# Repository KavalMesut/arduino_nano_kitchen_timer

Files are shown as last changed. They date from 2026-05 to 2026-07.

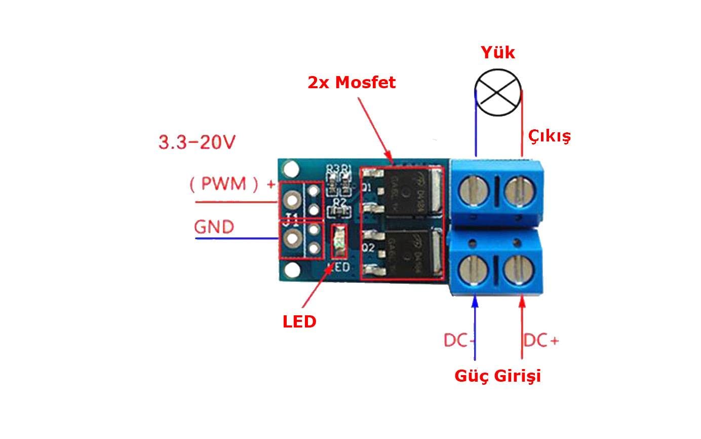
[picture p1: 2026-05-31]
mosfet.jpg

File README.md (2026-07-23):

# ⏳Mutfak Geri Sayım Alarmı (Arduino Nano & 18650 Li-ion Şarjlı Sürüm)

Bu proje, mutfakta çay demleme, yemek pişirme veya zaman gerektiren diğer hassas işler için tasarlanmış, döner enkoder (rotary encoder) kontrollü, TM1637 4 haneli 7 segment göstergeli, **18650 2200 mAh Li-ion Pil & LX-LCBST (TP4056 + DC-DC 5V Yükseltici)** şarj sistemli ve emniyetli MOSFET sürücülü 4 Ohm 5W güçlü hoparlör barındıran üst segment bir mutfak geri sayım alarmıdır.

Tüm sistem, taşınabilir şarjlı yapısı ve donanımsal/yazılımsal emniyet tedbirleriyle yüksek ses seviyesinde dahi kilitlenmemesi veya sıfırlanmaması için optimize edilmiştir.

---

## 🛠️ Kullanılan Malzemeler (BOM Listesi)

1. **Arduino Nano (CH340 veya Orijinal)**: Sistem durum makinesini (State Machine) yöneten ana kontrolcü.
2. **EC11 Bare Rotary Encoder (Döner Enkoder)**: Entegre mekanik butonu olan, süre ayarlamak ve komut vermek için kullanılan 360 derece dönebilen seçici.
3. **TM1637 4 Haneli 7 Segment Gösterge Modülü**: Zamanı `DAKİKA : SANİYE` (MM:SS) formatında ve batarya durumunu (`b-85`, `Lo`) gösteren ekran.
4. **4 Ohm 5W Güçlü Hoparlör**: Mutfaktaki gürültüde dahi çok net ve yüksek sesle duyulabilen kaliteli hoparlör.
5. **D4184 Dual MOSFET Anahtar Modülü**: Hoparlörü doğrudan Arduino pininden çekilemeyecek yüksek akımla, 5V hattından güvenle ve yüksek sesle tetiklemek için kullanılan mosfet kartı.
6. **18650 2200 mAh Li-ion Pil**: Şarj edilebilir ana güç kaynağı.
7. **LX-LCBST (TP4056 + DC-DC 5V Step-Up Yükseltici Modülü)**: Type-C şarj girişli, korumalı ve voltajı 5.0V'a yükseltilmiş şarj devresi.
8. **Sürgülü Güç Anahtarı (ON/OFF Switch)**: Cihazı tamamen açıp kapatan anahtar (LX-LCBST VO+ çıkışına seri bağlı).
9. **Emniyet Direnci**: Hoparlör bobinini ve MOSFET'i korurken yüksek ses sağlayan **2 adet 10 Ohm 1W paralel bağlı metal film koruma direnci (5Ω / 2W eşdeğer)**.
10. **A0 & A1 Koruma Dirençleri**: A0 (pil okuma) ve A1 (şarj algılama) pinleri öncesinde parazit beslemeyi ve pin hasarını önleyen **10kΩ seri koruma dirençleri**.
10. **Özel Tasarım 3D Kutu**: İçten içe 80mm x 140mm (Dıştan dışa 84mm x 144mm x 30mm) boyutlarında, baklava/diamond desenli hoparlör ızgaralı, Type-C şarj soketli ve M3 pirinç inserts (ısı kovanı) uyumlu gövde.

---

## ⚠️ KRİTİK TRİMPOT KALİBRASYON UYARISI

**LX-LCBST modülünün `VO+` / `VO-` çıkışlarını Arduino veya diğer kartlara bağlamadan önce;**
Modül üzerindeki minyatür trimpotu çevirerek `VO+` çıkış voltajını bir multimetre (avometre) ile ölçüp **tam 5.0 Volt'a** ayarlamalısınız! Aksi takdirde modül yüksek voltaj (9V/12V) vererek Arduino'ya zarar verebilir.

---

## 📐 3D Kutu ve Mekanik Özellikler

Kutu tasarımı OpenSCAD yardımıyla tamamen parametrik ve sağlam olarak geliştirilmiştir:
* **Gövde (`kutu_govde.stl`)**: Solid ön yüzey, 50mm baklava desenli hoparlör ızgarası, Type-C şarj soket yuvası, sağ yanda güç anahtarı yuvası ve köşelere tamamen gömülerek mukavemeti artırılmış **M3 pirinç ısı kovanı (heat-set inserts)** yuvaları barındırır.
* **Kapak (`kutu_kapak.stl`)**: Solid arka kapak, havşa başlı M3 vidaların sıfıra sıfır oturması için tasarlanmış delik yapıları.

---

## 🔋 Batarya & Şarj Ekran Özellikleri (TM1637)

* **2 Saniye Basılı Tutma (Batarya Kontrolü)**: Butona 2 saniye basılı tuttuğunuzda ekranda **tam 1 saniye boyunca** anlık batarya yüzdesi gösterilir (Örn: **`b-85`** = %85 pil), 1 saniye sonra ekran eski durumuna döner.
* **Düşük Batarya Uyarısı (%10 Altında `Lo` Uyarısı)**: Batarya seviyesi **%10'un altına** düştüğünde, her yeni zaman ayarlama girişiminde (enkoder her çevrildiğinde) ekranda **`Lo`** yazısı yanıp söner ve kısa bir **uyarı bip sesi** verilir.
* **Şarj Girişi Algılama**: Type-C takıldığında Arduino şarj modunu otomatik algılar.

---

## ⚡ Donanım Bağlantı Tablosu

| Kaynak Modül | Pin / Bağlantı | Hedef Pin | İşlev |
| :--- | :--- | :--- | :--- |
| **18650 Li-ion Pil** | Artı (+) / B+ | LX-LCBST B+ / **Arduino A0** | Batarya Besleme & Voltaj Okuma |
| **18650 Li-ion Pil** | Eksi (-) / B- | LX-LCBST B- | Batarya Şasi |
| **LX-LCBST Modülü** | VO+ (5V Yükseltici) | ON/OFF Anahtarı $\rightarrow$ **Ortak +5V** | 5.0V Sistem Besleme |
| **LX-LCBST Modülü** | VO- (GND) | **Ortak GND Rayı** | Sistem Şasi |
| **LX-LCBST Modülü** | IN+ (Type-C 5V) | 10k Direnç $\rightarrow$ **Arduino A1** | Şarj Girişi Algılama |
| **EC11 Enkoder** | Out A (3'lü Grup) | **Arduino D2** | Kesme 0 Sinyali |
| **EC11 Enkoder** | Out B (3'lü Grup) | **Arduino D3** | Kesme 1 Sinyali |
| **EC11 Enkoder** | Switch (2'li Grup) | **Arduino D4** | Buton Girişi |
| **TM1637 Ekran** | CLK / DIO | **Arduino D5 / D6** | Ekran Saat & Veri Hattı |
| **D4184 MOSFET** | (PWM) + Sinyal | **Arduino D9** | Timer 1 Donanımsal PWM Sinyali |

---

## 🚀 Derleme ve Kurulum

1. Bilgisayarınıza **Arduino IDE** kurun.
2. Arduino IDE içerisindeki **Kütüphane Yöneticisi (Library Manager)** menüsünden **TM1637** (Avishay Orpaz) kütüphanesini kurun.
3. [kitchen_timer.ino](file:///c:/Users/kaval/OneDrive/Desktop/geri%20say%C4%B1m%20nano/kitchen_timer/kitchen_timer.ino) dosyasını Arduino IDE ile açın.
4. Kart tipini **Arduino Nano**, işlemciyi ise klon kartlar için **ATmega328P (Old Bootloader)** seçin.
5. Uygun COM portunu belirleyip kodu kartınıza yükleyin.

---

## 📁 Proje Dosyaları Yapısı

* 📁 **`kitchen_timer/`**: Arduino kaynak dosyalarının bulunduğu klasör.
  * 📄 **`kitchen_timer.ino`**: Durum makinesi, kesme tabanlı enkoder okuma, MOSFET alarm ve A0/A1 batarya kodları.
* 📄 **`kutu_tasarimi.scad`**: OpenSCAD kutu tasarımının kaynak parametrik dosyası.
* 📄 **`kutu_govde.stl`**: Kutu gövdesinin 3D baskıya hazır modeli.
* 📄 **`kutu_kapak.stl`**: Arka kapağın 3D baskıya hazır modeli.
* 📄 **`baglanti_semasi.pdf` / `.tex`**: Detaylı donanım bağlantı kılavuzu ve şemaları.
* 📄 **`README.md`**: Proje açıklama ve kurulum dokümanı.

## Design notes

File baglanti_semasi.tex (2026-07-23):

\documentclass[12pt,a4paper]{article}
\usepackage[utf8]{inputenc}

\title{Arduino Nano ile Mutfak Geri Sayim Alarmi\\Sarjli/Bataryali Donanim Baglanti Kilavuzu}
\author{Mutfak Zamanlayici Projesi}
\date{23 Temmuz 2026}

\begin{document}

\maketitle

\section{Giris ve Onemli Guvenlik Uyarilari}
Bu belge, Arduino Nano tabanli, TM1637 7 segment gostergeli, EC11 doner enkoder kontrollu, D4184 MOSFET suruculu ve \textbf{18650 2200 mAh Li-ion Pil + LX-LCBST (TP4056 + DC-DC 5V Yukseltici)} sarj sistemli mutfak geri sayim alarminin baglanti detaylarini icermektedir.

\subsection{TRIMPOT KALIBRASYON UYARISI (COK ONEMLI!)}
\textbf{LX-LCBST modulunun VO+ / VO- cikislarini Arduino, ekran veya MOSFET kartina BAGLAMADAN ONCE;}
Type-C kablosunu veya pili takip bir multimetre (avometre) ile \textbf{VO+} cikis voltajini olcun. Modul uzerindeki minyatur trimpotu cevirerek cikis voltajini \textbf{tam 5.0 Volt'a} ayarlayin! Fabrikasyon olarak 9V/12V ayarli gelebilir; ayarlamadan baglarsaniz Arduino kartiniz ve ekraniniz yanabilir!

\subsection{Hoparlor ve MOSFET Emniyet Direnci}
4 Ohm 5W gucundeki hoparlorun yuksek anlik akim cekerek Arduino'ya reset attirmasini ve hoparlor bobininin zarar gormesini engellemek amaciyla hoparlor hattina seri olarak \textbf{10 Ohm (1W)} koruma direnci baglanmalidir.

\section{Adim Adim Baglanti Talimatlari}

\begin{enumerate}
    \item \textbf{Guc Kaynagi ve Sarj Sistemi (LX-LCBST + 18650 Pil):}
    \begin{itemize}
        \item \textbf{B+} $\rightarrow$ 18650 Pilin Arti (+) kutbuna ve ayni zamanda Arduino Nano \textbf{A0} pinine (Batarya voltaji okuma).
        \item \textbf{B-} $\rightarrow$ 18650 Pilin Eksi (-) kutbuna.
        \item \textbf{VO+} $\rightarrow$ Surgulu Guc Anahtarinin (ON/OFF) bacak 1'ine. Anahtarin bacak 2'si ortak \textbf{+5V} rayina baglanir.
        \item \textbf{VO-} $\rightarrow$ Ortak \textbf{GND} sasi rayina.
        \item \textbf{IN+} (Type-C Girisi) $\rightarrow$ 10k koruma direnci uzerinden Arduino Nano \textbf{A1} pinine (Sarj algilama).
        \item \textbf{IN-} (Type-C Sasi) $\rightarrow$ Ortak \textbf{GND} sasi rayina.
    \end{itemize}

    \item \textbf{Ciplak Doner Enkoder (EC11) Baglantilari:}
    \begin{itemize}
        \item \textbf{Out A} (Ust Pin - 3'lu grup) $\rightarrow$ Arduino Nano \textbf{D2}
        \item \textbf{GND} (Orta Pin - 3'lu grup) $\rightarrow$ Ortak \textbf{GND}
        \item \textbf{Out B} (Alt Pin - 3'lu grup) $\rightarrow$ Arduino Nano \textbf{D3}
        \item \textbf{Switch} (Sol Pin - 2'li grup) $\rightarrow$ Arduino Nano \textbf{D4}
        \item \textbf{GND} (Sag Pin - 2'li grup) $\rightarrow$ Ortak \textbf{GND}
    \end{itemize}

    \item \textbf{TM1637 Gosterge Baglantilari:}
    \begin{itemize}
        \item \textbf{CLK} $\rightarrow$ Arduino Nano \textbf{D5}
        \item \textbf{DIO} $\rightarrow$ Arduino Nano \textbf{D6}
        \item \textbf{VCC} $\rightarrow$ Ortak \textbf{+5V}
        \item \textbf{GND} $\rightarrow$ Ortak \textbf{GND}
    \end{itemize}

    \item \textbf{D4184 MOSFET Surucu \& Hoparlor Baglantilari:}
    \begin{itemize}
        \item \textbf{(PWM) +} Sinyal $\rightarrow$ Arduino Nano \textbf{D9}
        \item \textbf{Sinyal GND} $\rightarrow$ Ortak \textbf{GND}
        \item \textbf{DC+ (Klemens Alt Sag)} $\rightarrow$ Ortak \textbf{+5V}
        \item \textbf{DC- (Klemens Alt Sol)} $\rightarrow$ Ortak \textbf{GND}
        \item \textbf{Cikis+ (Klemens Ust Sag)} $\rightarrow$ Hoparlor (+)
        \item \textbf{Cikis- (Klemens Ust Sol)} $\rightarrow$ 10 Ohm 1W Direnc ucu 1
        \item 10 Ohm 1W Direnc ucu 2 $\rightarrow$ Hoparlor (-)
    \end{itemize}
\end{enumerate}

\newpage
\section{Donanim Baglanti Tablosu}

\begin{table}[h!]
\centering
\begin{tabular}{|l|l|l|l|}
\hline
\textbf{Kaynak Modul} & \textbf{Pin Adi} & \textbf{Hedef Pin / Baglanti} & \textbf{Islev} \\ \hline
18650 Li-ion Pil & Arti (+) / B+ & LX-LCBST B+ / Arduino A0 & Batarya Besleme \& Voltaj Okuma \\
18650 Li-ion Pil & Eksi (-) / B- & LX-LCBST B- & Batarya Sasi Baglantisi \\
LX-LCBST Modulu & VO+ (5V Cikis) & ON/OFF Anahtari $\rightarrow$ Ortak +5V & Ana Sistem Guc Cikisi \\
LX-LCBST Modulu & VO- (GND Cikis) & Ortak GND Sasi Rayi & Sistem Sasi Baglantisi \\
LX-LCBST Modulu & IN+ (Sarj Girisi) & 10k Direnc $\rightarrow$ Arduino A1 & Sarj Kablosu Algilama \\
LX-LCBST Modulu & IN- (Sarj Sasi) & Ortak GND Sasi Rayi & Sarj Girisi Sasisi \\ \hline
EC11 Enkoder & Out A (Ust - 3'lu) & Arduino Nano D2 & Zamanlama Girisi (Kesme 0) \\
EC11 Enkoder & GND (Orta - 3'lu) & Ortak GND & Enkoder Sasi \\
EC11 Enkoder & Out B (Alt - 3'lu) & Arduino Nano D3 & Yon Algilama (Kesme 1) \\
EC11 Enkoder & Switch (Sol - 2'li) & Arduino Nano D4 & Buton Girisi \\
EC11 Enkoder & GND (Sag - 2'li) & Ortak GND & Buton Sasi \\ \hline
TM1637 Ekran & CLK & Arduino Nano D5 & Gosterge Saat Sinyali \\
TM1637 Ekran & DIO & Arduino Nano D6 & Gosterge Veri Hatti \\
TM1637 Ekran & VCC & Ortak +5V Rayi & Gosterge Gucu \\
TM1637 Ekran & GND & Ortak GND Rayi & Gosterge Sasisi \\ \hline
D4184 MOSFET & (PWM) + Sinyal & Arduino Nano D9 & Sinyal Tetikleme (Timer 1) \\
D4184 MOSFET & Sinyal GND & Ortak GND & Ortak Sasi \\
D4184 MOSFET & DC+ (Alt Sag) & Ortak +5V Rayi & Hoparlor Guc Beslemesi \\
D4184 MOSFET & DC- (Alt Sol) & Ortak GND Rayi & Hoparlor Guc Sasisi \\
D4184 MOSFET & Cikis+ / Cikis- & 10 Ohm 1W Direnc ile Hoparlor & 5W Hoparlor Surucusu \\ \hline
\end{tabular}
\end{table}

\end{document}

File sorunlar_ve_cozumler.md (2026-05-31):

# 🛠️ Mutfak Geri Sayım Alarmı: Sorunlar ve Çözümler Kılavuzu

Bu belge, Arduino Nano tabanlı Premium Mutfak Geri Sayım Alarmı projesinin geliştirilmesi, montajı ve testleri sırasında karşılaşılan kritik elektriksel, donanımsal ve yazılımsal sorunları ve bu sorunların kesin çözümlerini bir araya getirmektedir. Gelecekteki bakım ve benzer projeler için bir başvuru kılavuzudur.

---

## 📌 1. Döner Enkoder Çift Atlama ve Gürültü Sorunu (Debouncing)

### 🔴 Belirti:
Enkoder döndürüldüğünde değerlerin kararsız artması/azalması, ara sıra çift atlamalar yapması veya hızlı çevrildiğinde adımların kaçırılması.

### 🔍 Analiz:
Mekanik döner enkoderler (bare EC11) döndürülürken elektriksel kontakları anlık olarak ark yapar (contact bounce). Bu yüksek frekanslı gürültüler kesme (interrupt) servisleri tarafından gerçek dönüş adımları gibi algılanır. 
* **Çok yüksek gürültü filtresi (örn. 20ms)** hızlı çevirmelerde adımların kaçırılmasına yol açar.
* **Çok düşük filtre (örn. 4ms)** gürültülü klon enkoderlerde çift atlamalara neden olur.

### 🟢 Kesin Çözüm:
Kesme servisi içerisindeki gürültü önleme filtresi **30 ms** olarak optimize edildi. Bu değer, klon enkoderlerin mekanik gürültülerini tamamen süzerken, normal çevrim hızlarındaki tüm adımların kararlı şekilde yakalanmasını sağlar:
```cpp
void encoderISR() {
  static unsigned long lastInterruptTime = 0;
  unsigned long interruptTime = millis();
  
  if (interruptTime - lastInterruptTime > 30) { // 30ms Kararlı Debounce
    int clkVal = digitalRead(PIN_ENC_CLK);
    int dtVal = digitalRead(PIN_ENC_DT);
    if (clkVal != dtVal) {
      encoderDelta = 1;
    } else {
      encoderDelta = -1;
    }
    encoderMoved = true;
    lastInterruptTime = interruptTime;
  }
}
```

---

## 📌 2. MOSFET Hoparlör Sürücü Emniyeti (DC Akım Koruması)

### 🔴 Belirti:
Hoparlör bobininin aşırı ısınması, MOSFET modülünün ısınması veya adaptörün aşırı akım korumasına girerek sistemi kapatması.

### 🔍 Analiz:
4 Ohm empedansa sahip güçlü bir hoparlör, 5V DC gerilim altında doğrudan iletimde kalırsa $I = V / R = 5V / 4\Omega = 1.25A$ akım çeker. Arduino Nano'nun pini kilitlenir veya yazılım hatasıyla sürekli `HIGH` konumda kalırsa, hoparlör bobini sürekli DC akıma maruz kalarak yanabilir.

### 🟢 Kesin Çözüm:
1. **Donanımsal Koruma (Direnç Hilesi):** Hoparlöre seri olarak **4 adet 47 Ohm 1/4W direnç paralel bağlanarak** (~11.7 Ohm 1W) seri koruma direnci oluşturuldu. Bu, çekilen akımı sınırlandırarak bobini korur.
2. **Yazılımsal Koruma (DC Emniyeti):** Ses üretimi tamamen AC/Pulsed mantığında (Timer PWM) yapıldı. Alarm çalmadığı veya ses durduğu anda MOSFET tetikleme pini (D9) donanımsal ve yazılımsal olarak tamamen kapatılıp `LOW` seviyesine çekilir:
```cpp
void stopTonePWM() {
  TCCR1A = 0; // Donanımsal PWM bağlantısını kopar
  TCCR1B = 0;
  digitalWrite(PIN_MOSFET, LOW); // Emniyet için pini LOW yap (Akımı tamamen keser)
}
```

---

## 📌 3. Fiziksel Temassızlık ve Akustik Titreşim (Kablo Kopukluğu)

### 🔴 Belirti:
Tetikleme LED'i yandığı halde hoparlörden hiçbir ses gelmemesi.

### 🔍 Analiz:
Klemens vidalarının plastik yalıtkanı sıkıştırması, lehim çatlakları veya hoparlörün ürettiği yüksek mekanik titreşimin (vibrasyon) kabloları sarsması sonucu oluşan gizli temassızlıklar.

### 🟢 Teşhis ve Çözüm Yöntemi (Yavaş Sinyal Testi):
Frekans yerine saniyede bir yavaşça açılıp kapanan (Blink) bir sinyal üretilerek klemens ve hoparlör yolları test edildi. Sinyal yavaşlatıldığında hoparlörden gelen **"tık... tık..."** sesleri sayesinde kopuk olan kablo noktası fiziksel olarak kolayca tespit edildi:
```cpp
// Yavaş tetikleme ile kablo ve lehim kontrolü yapılmıştır:
digitalWrite(9, HIGH); delay(1000);
digitalWrite(9, LOW);  delay(1000);
```

---

## 📌 4. Sürekli Ekran Yazımı Kaynaklı Döngü (Loop) Yavaşlaması

### 🔴 Belirti:
Siren çalarken veya zaman akarken döner enkoderin geç tepki vermesi, sistem zamanlamasında milisaniyelik kaymalar (jitter) oluşması.

### 🔍 Analiz:
TM1637 gösterge modülü yazılımsal bit-bang (CLK ve DIO pinlerini sırayla HIGH/LOW yapıp mikrosaniye seviyesinde bekleyerek) veri gönderir. Ekran verisi her `loop()` döngüsünde sürekli baştan yazıldığında, döngü hızı saniyede sadece ~200 çevrime düşer. Bu da mikrodenetleyicinin diğer zamanlayıcı işlerini geciktirir.

### 🟢 Kesin Çözüm:
Ekran güncelleme mekanizması **Olay Güdümlü (Event-Driven)** hale getirildi. Ekran verileri sadece **süre, durum veya iki noktanın konumu gerçekten değiştiğinde** yazılır. Bu sayede loop hızı **saniyede 50.000+ çevrime çıkarıldı**, gecikmeler tamamen yok edildi.

---

## 📌 5. Rastgele Siren Kesilmeleri (Timer 1 `ICR1` Aşım Hatası)

### 🔴 Belirti:
Alarm çalarken, belirli aralıklarla olmayan, tamamen rastgele ve düzensiz milisaniyelik anlık ses kesilmeleri/pıtırtılar oluşması.

### 🔍 Analiz:
Siren tonunu 2500 Hz ile 3500 Hz arasında 100 ms'de bir değiştirmek için Timer 1'in **`ICR1` (Üst Sınır / TOP)** kaydedicisine yeni değer yazılır. 
* ATmega328P mimarisinde Fast PWM modunda (Mod 14) **`ICR1` kaydedicisi donanımsal çift-tamponlu (double-buffered) değildir.** Değer yazıldığı anda güncellenir.
* **Hata Durumu:** Frekansı değiştirirken eğer Timer 1 sayacı (`TCNT1`) o an yeni yazılan `ICR1` sınırını geçmişse (örn. TCNT1=600, yeni ICR1=571), sayaç üst sınırı kaçırır. Sınırı kaçırdığı için durmaz ve taa **65535'e kadar saymaya devam eder**.
* Bu durum, 2 MHz sayaç hızında tam **32.7 milisaniye** sürer ve bu süre zarfında MOSFET kapısı takılı kalarak **rastgele ve periyodik olmayan sessizlik/kesinti** oluşturur.

### 🟢 Kesin Çözüm:
Frekans (yani `ICR1`) her değiştiğinde, zamanlayıcı sayacı yazılımsal olarak **anında sıfırlanır (`TCNT1 = 0;`)**. Böylece sayaç asla yeni üst sınırı kaçırmaz ve geçişler faz-kesintisiz, tamamen pürüzsüz ve çıtırtısız olur:
```cpp
void startTonePWM(unsigned int frequency, int volumeLevel) {
  pinMode(PIN_MOSFET, OUTPUT);
  unsigned long top = 2000000UL / frequency;
  
  if (ICR1 != top) {
    ICR1 = top;
    TCNT1 = 0; // Sayacı sıfırlayarak TCNT1 > ICR1 aşımını engeller (Kesintileri sıfırlar!)
  }
  
  unsigned long ocr = (top * (unsigned long)(volumeLevel * volumeLevel)) / 200UL;
  if (ocr == 0 && volumeLevel > 0) ocr = 1;
  OCR1A = ocr;
  
  if ((TCCR1A & _BV(COM1A1)) == 0) {
    TCCR1A = _BV(COM1A1) | _BV(WGM11);
    TCCR1B = _BV(WGM13) | _BV(WGM12) | _BV(CS11);
  }
}
```

---

## 🛠️ Gelecekte Yapılacak Değişiklik: Test Modunu Kapatma

Şu anda ses ve donanım montajını hızlıca test edebilmeniz için kodda **3 saniyelik hızlı test modu** aktiftir. Montajı tamamlayıp sistemi nihai durumuna getirdiğinizde bu modu kapatmak için şu iki basit adımı uygulayın:

### 1. Adım:
[kitchen_timer.ino](file:///C:/Users/kaval/OneDrive/Desktop/geri%20say%C4%B1m%20nano/kitchen_timer/kitchen_timer.ino) dosyasının en başındaki (satır 38 civarı) varsayılan süreyi **`0`** yapın:
```diff
- #define DEFAULT_TIME_SECONDS 3
+ #define DEFAULT_TIME_SECONDS 0
```

### 2. Adım:
Dosyanın sonundaki `loadTimeFromEEPROM()` fonksiyonundaki (satır 627 civarı) geçici kontrol bloğunu silin veya yorum satırı yapın:
```diff
 void loadTimeFromEEPROM() {
   byte magic = EEPROM.read(EEPROM_ADDR_MAGIC);
   
   if (magic == EEPROM_MAGIC_VAL) {
     byte loadedMinutes = EEPROM.read(EEPROM_ADDR_TIME);
     if (loadedMinutes >= MIN_MINUTES && loadedMinutes <= MAX_MINUTES) {
-      // [GEÇİCİ TEST] Eğer kalıcı hafızadaki süre 0 ise hızlı test kolaylığı için 3 saniye yapalım
-      if (loadedMinutes == 0) {
-        targetTimeSeconds = 3;
-        return;
-      }
       targetTimeSeconds = (long)loadedMinutes * 60;
       return;
     }
   }
   
   targetTimeSeconds = DEFAULT_TIME_SECONDS;
 }
```
Bu adımları uyguladığınızda cihazınız tamamen orijinal, bekleme modunda `00:00` ile başlayan normal çalışma döngüsüne geri dönecektir.

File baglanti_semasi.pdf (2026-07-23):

# Arduino Nano ile Mutfak Geri Sayim Alarmi Sarjli/Bataryali Donanim Baglanti Kilavuzu

### Mutfak Zamanlayici Projesi

### 23 Temmuz 2026

## 1 Giris ve Onemli Guvenlik Uyarilari

Bu belge, Arduino Nano tabanli, TM1637 7 segment gostergeli, EC11 doner enkoder kontrollu, D4184 MOSFET suruculu ve 18650 2200 mAh Li-ion Pil + LX-LCBST (TP4056 + DC-DC 5V Yukseltici) sarj sistemli mutfak geri sayim alarminin baglanti detaylarini icermektedir.

### 1.1 TRIMPOT KALIBRASYON UYARISI (COK ONEMLI!)

LX-LCBST modulunun VO+ / VO- cikislarini Arduino, ekran veya
MOSFET kartina BAGLAMADAN ONCE; Type-C kablosunu veya
pili takip bir multimetre (avometre) ile VO+ cikis voltajini olcun. Modul uzerindeki minyatur trimpotu cevirerek cikis voltajini tam 5.0 Volt’a ayarlayin! Fabrikasyon olarak 9V/12V ayarli gelebilir; ayarlamadan baglarsaniz Arduino kartiniz ve ekraniniz yanabilir!

### 1.2 Hoparlor ve MOSFET Emniyet Direnci

4 Ohm 5W gucundeki hoparlorun yuksek anlik akim cekerek Arduino’ya reset attirmasini ve hoparlor bobininin zarar gormesini engellemek amaciyla hoparlor hattina seri olarak 10 Ohm (1W) koruma direnci baglanmalidir.

## 2 Adim Adim Baglanti Talimatlari

1. Guc Kaynagi ve Sarj Sistemi (LX-LCBST + 18650 Pil):
| B+ → 18650 Pilin Arti (+) kutbuna ve ayni zamanda Arduino Nano A0 pinine (Batarya voltaji okuma).
| 1

| B- → 18650 Pilin Eksi (-) kutbuna.
| VO+ → Surgulu Guc Anahtarinin (ON/OFF) bacak 1’ine. Anahtarin bacak 2’si ortak +5V rayina baglanir.
| VO- → Ortak GND sasi rayina.
| IN+ (Type-C Girisi) → 10k koruma direnci uzerinden Arduino Nano A1 pinine (Sarj algilama).
| IN- (Type-C Sasi) → Ortak GND sasi rayina.
2. Ciplak Doner Enkoder (EC11) Baglantilari:
| Out A (Ust Pin - 3’lu grup) → Arduino Nano D2
| GND (Orta Pin - 3’lu grup) → Ortak GND
| Out B (Alt Pin - 3’lu grup) → Arduino Nano D3
| Switch (Sol Pin - 2’li grup) → Arduino Nano D4
| GND (Sag Pin - 2’li grup) → Ortak GND
3. TM1637 Gosterge Baglantilari:
| CLK → Arduino Nano D5
| DIO → Arduino Nano D6
| VCC → Ortak +5V
| GND → Ortak GND
4. D4184 MOSFET Surucu & Hoparlor Baglantilari:
| (PWM) + Sinyal → Arduino Nano D9
| Sinyal GND → Ortak GND
| DC+ (Klemens Alt Sag) → Ortak +5V
| DC- (Klemens Alt Sol) → Ortak GND
| Cikis+ (Klemens Ust Sag) → Hoparlor (+)
| Cikis- (Klemens Ust Sol) → 10 Ohm 1W Direnc ucu 1
| 10 Ohm 1W Direnc ucu 2 → Hoparlor (-)

2

## 3 Donanim Baglanti Tablosu

Kaynak Modul | Pin Adi | Hedef Pin / Baglanti | Islev
18650 Li-ion Pil | Arti (+) / B+ | LX-LCBST B+ / Arduino A0 | Batarya Besleme & Voltaj Okuma
18650 Li-ion Pil | Eksi (-) / B- | LX-LCBST B- | Batarya Sasi Baglantisi
LX-LCBST Modulu | VO+ (5V Cikis) | ON/OFF Anahtari → Ortak +5V | Ana Sistem Guc Cikisi
LX-LCBST Modulu | VO- (GND Cikis) | Ortak GND Sasi Rayi | Sistem Sasi Baglantisi
LX-LCBST Modulu | IN+ (Sarj Girisi) | 10k Direnc → Arduino A1 | Sarj Kablosu Algilama
LX-LCBST Modulu | IN- (Sarj Sasi) | Ortak GND Sasi Rayi | Sarj Girisi Sasisi
EC11 Enkoder | Out A (Ust - 3’lu) | Arduino Nano D2 | Zamanlama Girisi (Kesme 0)
EC11 Enkoder | GND (Orta - 3’lu) | Ortak GND | Enkoder Sasi
EC11 Enkoder | Out B (Alt - 3’lu) | Arduino Nano D3 | Yon Algilama (Kesme 1)
EC11 Enkoder | Switch (Sol - 2’li) | Arduino Nano D4 | Buton Girisi
EC11 Enkoder | GND (Sag - 2’li) | Ortak GND | Buton Sasi
TM1637 Ekran | CLK | Arduino Nano D5 | Gosterge Saat Sinyali
TM1637 Ekran | DIO | Arduino Nano D6 | Gosterge Veri Hatti
TM1637 Ekran | VCC | Ortak +5V Rayi | Gosterge Gucu
TM1637 Ekran | GND | Ortak GND Rayi | Gosterge Sasisi
D4184 MOSFET | (PWM) + Sinyal | Arduino Nano D9 | Sinyal Tetikleme (Timer 1)
D4184 MOSFET | Sinyal GND | Ortak GND | Ortak Sasi
D4184 MOSFET | DC+ (Alt Sag) | Ortak +5V Rayi | Hoparlor Guc Beslemesi
D4184 MOSFET | DC- (Alt Sol) | Ortak GND Rayi | Hoparlor Guc Sasisi
D4184 MOSFET | Cikis+ / Cikis- | 10 Ohm 1W Direnc ile Hoparlor | 5W Hoparlor Surucusu

3

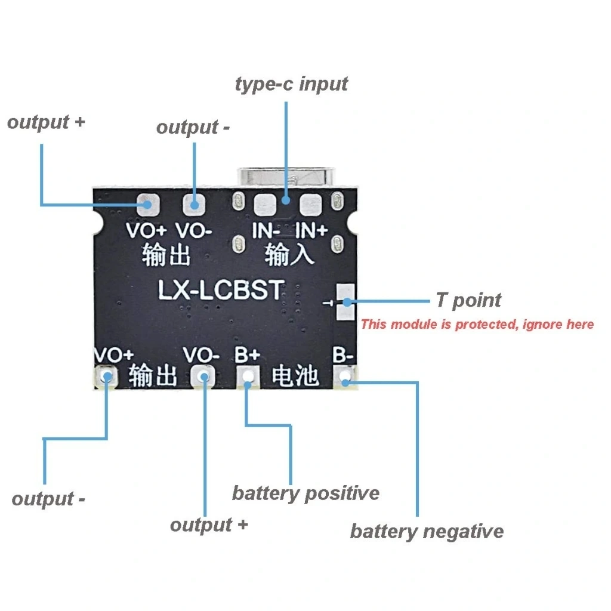
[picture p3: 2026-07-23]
TP4056_dc_dc_voltaj_ayarli_arka_yuz.png

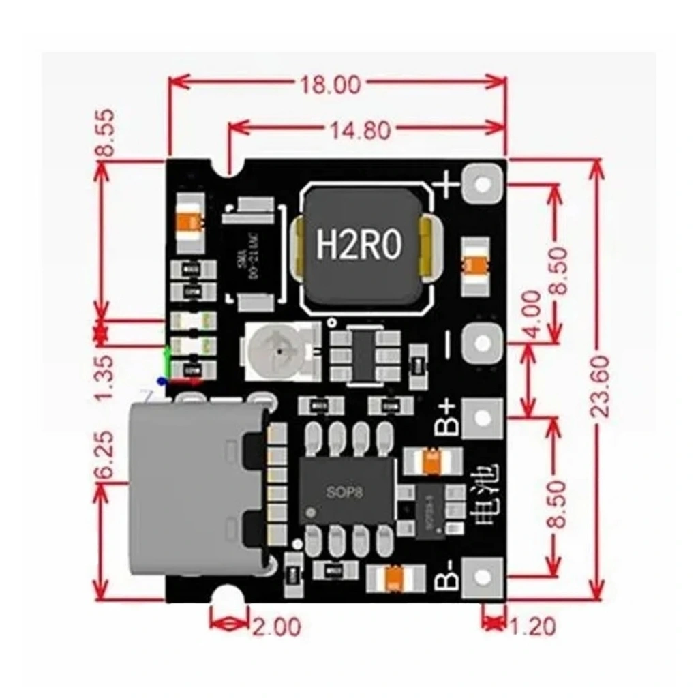
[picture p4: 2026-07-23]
TP4056_dc_dc_voltaj_ayarli.png

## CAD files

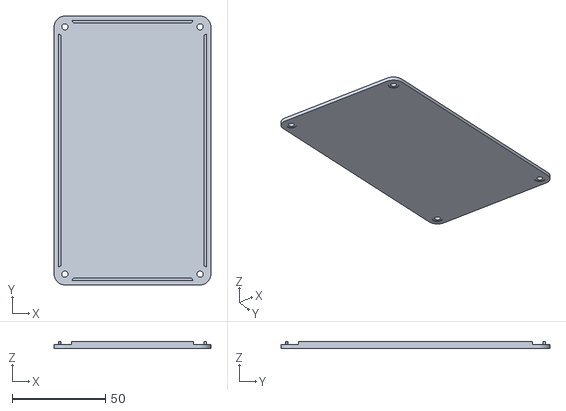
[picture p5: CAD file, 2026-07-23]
kutu_kapak.stl
84.0 x 144.0 x 3.50

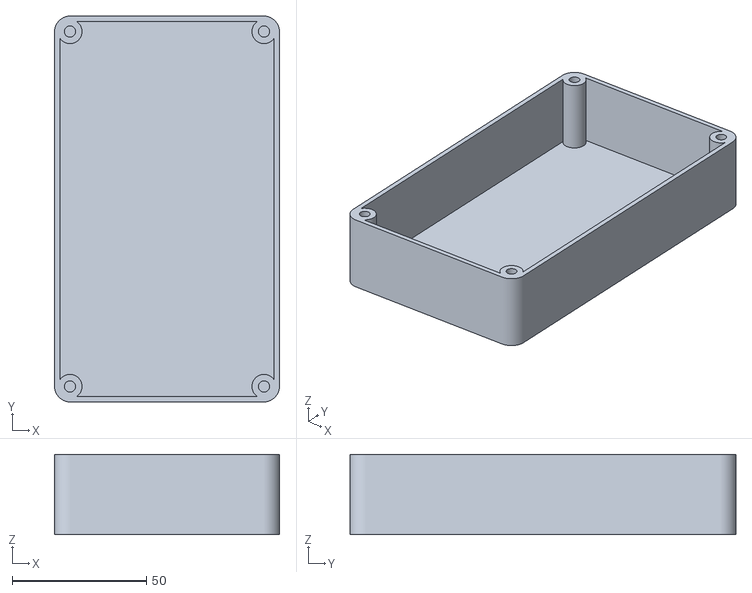
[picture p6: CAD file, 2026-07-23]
kutu_govde.stl
84.0 x 144.0 x 30.0

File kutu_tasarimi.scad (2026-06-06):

// =========================================================================
// MUTFAK GERİ SAYIM ALARMI - DİKEY ELEGAN 3D KUTU TASARIMI (OpenSCAD)
// =========================================================================
// Tasarım Özellikleri:
// - Dikey Form Faktörü: 60mm Genişlik x 100mm Yükseklik x 45mm Derinlik
// - Sol Üst: Döner Enkoder Mili
// - Sağ Üst: TM1637 Yatay Gösterge Penceresi
// - Alt Orta: Dairesel Baklava Izgarası (50mm Çap / 25mm Yarıçap)
// - Sağ Duvar: Güç Açma/Kapama Sürgülü Anahtar Yuvası
// - Alt Duvar: Type-C Şarj Kablosu Yuvası
// - Bağlantılar: M3 Pirinç Isıtmalı Dişli İnsert (Brass Heat-Set Insert) Uyumlu
// =========================================================================

$fn = 180; // Daire kalitesi (Pürüzsüzlük için en üst seviye - Tinkercad "Sides" maksimum)

// --- RENDER SEÇENEĞİ ---
// "govde"   -> Ön panel delikli dikey ana kutu gövdesi
// "kapak"   -> M3 vidalı havşalı arka kapak kapağı
// "montaj"  -> İki parçanın montaja hazır patlatılmış önizlemesi
secilen_parca = "montaj"; // [govde, kapak, montaj]

// --- KUTU BOYUTLARI ---
duvar = 2.0;     // Kutu et/duvar kalınlığı
kutu_g = 80.0 + 2 * duvar;   // Dış Genişlik (İç genişlik 80mm + 2 * duvar)
kutu_y = 140.0 + 2 * duvar;  // Dış Yükseklik (İç yükseklik 140mm + 2 * duvar)
kutu_d = 30.0;   // Dış Derinlik (Z ekseni)
r_kose = 6.0;    // Köşelerin yuvarlatılma yarıçapı

// --- ELEMAN KESİK BOYUTLARI ---
// TM1637 Ekran Penceresi (Yatay)
ekran_g = 30.6;  
ekran_y = 14.2;

// EC11 Enkoder Deliği (Dişli şaft için 7.2mm)
enkoder_d = 7.2;

// Type-C Şarj Girişi Yuvası (Alt duvarda, ortalanmış)
sarj_g = 11.0;
sarj_y = 4.5;

// Sürgülü Güç Anahtarı Yuvası (Sağ duvarda)
anahtar_g = 10.0;
anahtar_y = 5.0;

// M3 Pirinç İnsert Ölçüleri (Heat-Set Insert)
insert_d = 4.2;      // M3 insert için önerilen yuva çapı (Havya ile eritmek için tam karar)
insert_derinlik = 8.5; // Insertün rahat oturması için derinlik
vida_gecis_d = 3.3;   // M3 vidanın kapaktan rahat geçmesi için çap
vida_baslik_d = 6.0;  // M3 havşa vida başlığı yuva çapı

// --- ÇEKİRDEK KODLAR ---

module yuvarlatilmis_kutu(g, y, d, r) {
    hull() {
        translate([r, r, 0]) cylinder(r=r, h=d);
        translate([g - r, r, 0]) cylinder(r=r, h=d);
        translate([r, y - r, 0]) cylinder(r=r, h=d);
        translate([g - r, y - r, 0]) cylinder(r=r, h=d);
    }
}

// 1. ANA DİKEY GÖVDE
module kutu_govdesi() {
    difference() {
        // Ana Dış Kasa
        yuvarlatilmis_kutu(kutu_g, kutu_y, kutu_d, r_kose);
        
        // İç Boşluk (Duvar kalınlığı düşülmüş)
        translate([duvar, 
                   duvar, 
                   duvar])
        yuvarlatilmis_kutu(kutu_g - 2*duvar, 
                           kutu_y - 2*duvar, 
                           kutu_d,                            r_kose - duvar);
        
        // --- ÖN PANEL KESİKLERİ ---
        // (Ön panel tamamen düz ve kapalı yapılmıştır, delikleri kullanıcı kendi tasarımına göre ekleyecektir)

        // --- ALT VE SAĞ DUVAR KESİKLERİ ---
        // (Soket ve anahtar delikleri kaldırılmıştır, kullanıcı dış çeperi kendi tasarlayacaktır)
    }
    
    // --- KAPAK İÇİN M3 PİRİNÇ İNSERT KULELERİ (4 Köşede) ---
    // Pirinç insertlerin sağlam erimesi için dış çapı 9mm yapılmıştır.
    difference() {
        union() {
            // Sol Alt Kule
            translate([duvar + 3.8, duvar + 3.8, duvar])
            cylinder(d=9, h=kutu_d - duvar);
            
            // Sağ Alt Kule
            translate([kutu_g - (duvar + 3.8), duvar + 3.8, duvar])
            cylinder(d=9, h=kutu_d - 2);
            
            // Sol Üst Kule
            translate([duvar + 3.8, kutu_y - (duvar + 3.8), duvar])
            cylinder(d=9, h=kutu_d - 2);
            
            // Sağ Üst Kule
            translate([kutu_g - (duvar + 3.8), kutu_y - (duvar + 3.8), duvar])
            cylinder(d=9, h=kutu_d - 2);
        }
        // Isıtmalı M3 insertün havya ile eriyerek girmesi için 4.2mm çapında kılavuz delikler
        translate([duvar + 3.8, duvar + 3.8, kutu_d - insert_derinlik]) cylinder(d=insert_d, h=insert_derinlik + 1);
        translate([kutu_g - (duvar + 3.8), duvar + 3.8, kutu_d - insert_derinlik]) cylinder(d=insert_d, h=insert_derinlik + 1);
        translate([duvar + 3.8, kutu_y - (duvar + 3.8), kutu_d - insert_derinlik]) cylinder(d=insert_d, h=insert_derinlik + 1);
        translate([kutu_g - (duvar + 3.8), kutu_y - (duvar + 3.8), kutu_d - insert_derinlik]) cylinder(d=insert_d, h=insert_derinlik + 1);
    }
}

// 2. ARKA KAPAK (M3 Vidalar İçin Havşalı Delikli - Düz Yüzey)
module kutu_kapagi() {
    difference() {
        // Kapak Ana Plakası (Düz ve Pürüzsüz)
        yuvarlatilmis_kutu(kutu_g, kutu_y, duvar, r_kose);
        
        // 4 Köşedeki Vida Geçiş Delikleri (3.3mm temiz geçiş + 6mm havşa baş yuvası)
        translate([duvar + 3.8, duvar + 3.8, -1]) {
            cylinder(d=vida_gecis_d, h=duvar + 2);
            cylinder(d=vida_baslik_d, h=1.3); // Havşa yuvası
        }
        translate([kutu_g - (duvar + 3.8), duvar + 3.8, -1]) {
            cylinder(d=vida_gecis_d, h=duvar + 2);
            cylinder(d=vida_baslik_d, h=1.3);
        }
        translate([duvar + 3.8, kutu_y - (duvar + 3.8), -1]) {
            cylinder(d=vida_gecis_d, h=duvar + 2);
            cylinder(d=vida_baslik_d, h=1.3);
        }
        translate([kutu_g - (duvar + 3.8), kutu_y - (duvar + 3.8), -1]) {
            cylinder(d=vida_gecis_d, h=duvar + 2);
            cylinder(d=vida_baslik_d, h=1.3);
        }
    }
    
    // Kapağın yerine sıkı oturmasını ve kaymamasını sağlayan iç kılavuz çerçeve
    difference() {
        translate([duvar + 0.3, duvar + 0.3, duvar])
        yuvarlatilmis_kutu(kutu_g - 2*(duvar + 0.3), kutu_y - 2*(duvar + 0.3), 1.5, r_kose - (duvar + 0.3));
        
        translate([duvar + 1.8, duvar + 1.8, duvar - 1])
        yuvarlatilmis_kutu(kutu_g - 2*(duvar + 1.8), kutu_y - 2*(duvar + 1.8), 4, r_kose - (duvar + 1.8));
        
        // Vida kulelerinin geçmesi için iç çerçevedeki dairesel köşe kesikleri
        translate([duvar + 3.8, duvar + 3.8, 0]) cylinder(d=10, h=5);
        translate([kutu_g - (duvar + 3.8), duvar + 3.8, 0]) cylinder(d=10, h=5);
        translate([duvar + 3.8, kutu_y - (duvar + 3.8), 0]) cylinder(d=10, h=5);
        translate([kutu_g - (duvar + 3.8), kutu_y - (duvar + 3.8), 0]) cylinder(d=10, h=5);
    }
}

// --- RENDER SEÇENEKLERİ ---
if (secilen_parca == "govde") {
    kutu_govdesi();
} 
else if (secilen_parca == "kapak") {
    kutu_kapagi();
} 
else if (secilen_parca == "montaj") {
    // Montajlı görünüm: Mavi gövde, yeşil kapak yukarıda patlatılmış görünümde
    color("LightBlue", 0.8) kutu_govdesi();
    
    color("LightGreen", 0.9)
    translate([0, 0, kutu_d + 15]) 
    kutu_kapagi();
}

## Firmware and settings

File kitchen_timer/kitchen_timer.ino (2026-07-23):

/**
 * KİTCHEN COUNTDOWN TIMER / MUTFAK GERİ SAYIM ALARMI (ŞARJLI / BATARYALI SÜRÜM)
 * Donanım: Arduino Nano, TM1637 Display, Rotary Encoder, MOSFET Sürücü & 4 Ohm 5W Hoparlör,
 *          18650 2200 mAh Li-ion Pil & LX-LCBST (TP4056 + DC-DC 5V Yükseltici Modülü)
 * 
 * ÖNEMLİ ELEKTRİKSEL NOT:
 * 4 Ohm 5W hoparlörün MOSFET ile 5V'ta yüksek sesli ve güvenli çalışması için 
 * 2 adet 10 Ohm 1W direnç birbirine PARALEL bağlanmalıdır (5 Ohm / 2W eşdeğer). 
 * Bu paralel direnç bloğu hem sesi yükseltir hem de hoparlörünüzü ve MOSFET'inizi korur.
 * 
 * BATARYA & ŞARJ YÖNETİMİ:
 * - A0 Pini: 18650 Pil (B+) Voltaj Okuma (3.0V - 4.2V -> %0 - %100)
 * - A1 Pini: Type-C Şarj Girişi Algılama (IN+)
 * - 2 saniye basılı tutulduğunda 1 saniye boyunca ekranda anlık pil yüzdesi gösterilir (Örn: b-85).
 * - Batarya %10'un altına düştüğünde her yeni zaman ayarlama girişiminde "Lo" yanıp söner ve uyarı bip sesi verir.
 */

#include <Arduino.h>
#include <TM1637Display.h>
#include <EEPROM.h>

// PIN TANIMLAMALARI
#define PIN_ENC_CLK  2   // Kesme (Interrupt) pini - Döner Enkoder A Çıkışı
#define PIN_ENC_DT   3   // Kesme (Interrupt) pini - Döner Enkoder B Çıkışı
#define PIN_ENC_SW   4   // Döner Enkoder Entegre Buton Çıkışı
#define PIN_DISP_CLK 5   // TM1637 Clock Pini
#define PIN_DISP_DIO 6   // TM1637 Data Pini
#define PIN_MOSFET   9   // MOSFET Sinyal Pini (Hoparlör Tetikleyici)
#define PIN_BATTERY_SENSE A0 // 18650 Batarya Voltaj Okuma Pini (B+) [YENİ]
#define PIN_CHARGER_SENSE A1 // Type-C Şarj Girişi Algılama Pini (IN+) [YENİ]

// EEPROM Bellek Adresleri
#define EEPROM_ADDR_MAGIC        10  // Belleğin daha önce yazılıp yazılmadığını kontrol etmek için sihirli bayt
#define EEPROM_ADDR_TIME         0   // Sürenin kaydedileceği adres (unsigned long veya int)
#define EEPROM_MAGIC_VAL         0xA6
#define EEPROM_ADDR_VOLUME       1   // Ses seviyesinin kaydedileceği adres
#define EEPROM_ADDR_VOLUME_MAGIC 11  // Ses seviyesi geçerlilik magic adresi
#define EEPROM_VOLUME_MAGIC_VAL  0x5A

// Sınır Değerler (Süre dakika cinsinden ayarlandığı için 0-99 dk arası)
#define MAX_MINUTES 99
#define MIN_MINUTES 0
#define DEFAULT_TIME_SECONDS 0 // Varsayılan başlangıç süresi 0 dakika (0 saniye)

// Sistem Durumları (State Machine)
enum SystemState {
  STATE_STANDBY,        // Bekleme Modu (Son süre gösterilir, noktalar yavaşça yanıp söner)
  STATE_ADJUSTING,      // Süre Ayarlama Modu (Döndürüldüğünde girilir, süre ayarlanır)
  STATE_COUNTDOWN,      // Geri Sayım Aktif
  STATE_PAUSED,         // Geri Sayım Duraklatıldı
  STATE_ALARM,          // Alarm Aktif (Süre bitti, hoparlör ötüyor)
  STATE_VOLUME_SETTING, // Ses Seviyesi Ayarlama Modu
  STATE_BATTERY_SHOW    // Batarya Yüzdesi Gösterim Modu (1 saniye sürer) [YENİ]
};

// Enkoder Buton Olayları
enum ButtonEvent {
  BTN_NONE,
  BTN_SHORT,     // Kısa basış (<1 sn)
  BTN_LONG,      // 1 saniye basış (Ses Ayarı)
  BTN_VERY_LONG  // 2 saniye basış (1 sn Batarya Yüzdesi Gösterimi) [YENİ]
};

// Global Değişkenler
SystemState currentState = STATE_STANDBY;
SystemState previousState = STATE_STANDBY; // Ses/Batarya ayarlarından geri dönüş için
long targetTimeSeconds = DEFAULT_TIME_SECONDS; // Ayarlanan hedef süre (saniye)
long remainingSeconds = DEFAULT_TIME_SECONDS;  // Kalan süre (saniye)

// TM1637 Ekran Nesnesi
TM1637Display display(PIN_DISP_CLK, PIN_DISP_DIO);

// Volatile Enkoder Değişkenleri (Kesme içerisinde değiştirildiği için)
volatile int encoderDelta = 0; 
volatile bool encoderMoved = false;

// Zamanlayıcı Takip Değişkenleri
unsigned long lastCountdownTick = 0;
unsigned long lastStateChangeTime = 0;
unsigned long lastColonToggle = 0;
bool colonState = false;
unsigned long batteryShowStartTime = 0; // 1 saniyelik batarya ekranı sayacı [YENİ]
unsigned long lowBatteryAlertTime = 0;  // Düşük batarya Lo uyarısı sayacı [YENİ]
bool showingLowBatteryAlert = false;

// Alarm Ses Ritmi Değişkenleri
unsigned long lastAlarmActionTime = 0;
int alarmPatternState = 0; 

// Alarm Sırasında Ekran Efekti Değişkenleri
unsigned long lastAlarmDisplayToggle = 0;
bool alarmDisplayToggleState = false;

// TM1637 Segment Tanımları
const uint8_t SEG_END[] = { 0x79, 0x54, 0x5E, 0x00 }; // "End "
const uint8_t SEG_ALRT[] = { 0x77, 0x38, 0x50, 0x78 }; // "ALrt"
const uint8_t SEG_LO[]   = { 0x00, 0x38, 0x5C, 0x00 }; // " Lo " (Düşük Batarya) [YENİ]
const uint8_t SEG_CHRG[] = { 0x58, 0x74, 0x50, 0x6F }; // "chrg" (Şarj Oluyor) [YENİ]
const uint8_t SEG_FULL[] = { 0x71, 0x3E, 0x38, 0x38 }; // "FULL" (Tam Dolu) [YENİ]

// Ses Ayarı Değişkenleri
int volumeLevel = 5; // Varsayılan ses seviyesi (1-10 arası, 5 = orta)

// --- FONKSİYON PROTOTİPLERİ ---
void encoderISR();
ButtonEvent checkButton();
void updateDisplay();
void handleAlarmSpeaker();
void saveTimeToEEPROM();
void loadTimeFromEEPROM();
void saveVolumeToEEPROM();
void loadVolumeFromEEPROM();
void startTonePWM(unsigned int frequency, int volumeLevel);
void stopTonePWM();
int getBatteryPercentage();
bool isChargerPlugged();

void setup() {
  // Teşhis için dahili LED çıkış yapılıyor
  pinMode(LED_BUILTIN, OUTPUT);
  digitalWrite(LED_BUILTIN, LOW);

  // Pin modları ayarlanıyor
  pinMode(PIN_ENC_CLK, INPUT_PULLUP);
  pinMode(PIN_ENC_DT, INPUT_PULLUP);
  pinMode(PIN_ENC_SW, INPUT_PULLUP);
  pinMode(PIN_BATTERY_SENSE, INPUT);
  pinMode(PIN_CHARGER_SENSE, INPUT);
  
  // Hoparlör pini çıkış yapılıyor ve LOW tutuluyor
  pinMode(PIN_MOSFET, OUTPUT);
  digitalWrite(PIN_MOSFET, LOW);

  // TM1637 Ekranı Başlatılıyor
  display.setBrightness(4);
  
  // Kalıcı hafızadan son süreyi ve ses seviyesini yükle
  loadTimeFromEEPROM();
  loadVolumeFromEEPROM();
  remainingSeconds = targetTimeSeconds;

  // Enkoder Kesmesi
  attachInterrupt(digitalPinToInterrupt(PIN_ENC_CLK), encoderISR, CHANGE);
  
  lastStateChangeTime = millis();
}

void loop() {
  digitalWrite(LED_BUILTIN, digitalRead(PIN_ENC_SW) == LOW ? HIGH : LOW);

  unsigned long currentMillis = millis();
  int batPct = getBatteryPercentage();

  // 1. Döner Enkoder Dönüş Hareketinin İşlenmesi
  if (encoderMoved) {
    noInterrupts();
    int delta = encoderDelta;
    encoderDelta = 0;
    encoderMoved = false;
    interrupts();

    if (delta != 0) {
      lastStateChangeTime = currentMillis;

      // Batarya %10'un altındaysa her zaman ayarlama girişiminde Lo uyarısı ve bip sesi ver [YENİ]
      if (batPct < 10 && !isChargerPlugged()) {
        showingLowBatteryAlert = true;
        lowBatteryAlertTime = currentMillis;
        startTonePWM(2000, volumeLevel);
        delay(80);
        stopTonePWM();
      }

      if (currentState == STATE_VOLUME_SETTING) {
        volumeLevel += delta;
        if (volumeLevel > 10) volumeLevel = 10;
        if (volumeLevel < 1) volumeLevel = 1;

        startTonePWM(3000, volumeLevel);
        delay(50);
        stopTonePWM();
      } 
      else {
        if (currentState == STATE_ALARM) {
          currentState = STATE_STANDBY;
          remainingSeconds = targetTimeSeconds;
        } 
        else if (currentState == STATE_COUNTDOWN || currentState == STATE_PAUSED) {
          currentState = STATE_ADJUSTING;
        }
        else if (currentState == STATE_STANDBY) {
          currentState = STATE_ADJUSTING;
        }

        // Dinamik adım boyutu
        if (delta > 0) {
          if (targetTimeSeconds < 30) {
            targetTimeSeconds = 30;
          } else if (targetTimeSeconds < 60) {
            targetTimeSeconds = 60;
          } else {
            long stepSeconds = (targetTimeSeconds >= 30 * 60) ? 300 : 60;
            targetTimeSeconds += stepSeconds;
          }
        } else {
          if (targetTimeSeconds <= 30) {
            targetTimeSeconds = 0;
          } else if (targetTimeSeconds <= 60) {
            targetTimeSeconds = 30;
          } else {
            long stepSeconds = (targetTimeSeconds > 30 * 60) ? 300 : 60;
            targetTimeSeconds -= stepSeconds;
          }
        }

        if (targetTimeSeconds > (MAX_MINUTES * 60)) {
          targetTimeSeconds = MAX_MINUTES * 60;
        }
        if (targetTimeSeconds < (MIN_MINUTES * 60)) {
          targetTimeSeconds = MIN_MINUTES * 60;
        }
        
        remainingSeconds = targetTimeSeconds;
      }
    }
  }

  // 2. Buton Tıklamalarının İşlenmesi
  ButtonEvent btn = checkButton();
  if (btn != BTN_NONE) {
    lastStateChangeTime = currentMillis;

    // Batarya %10'un altındaysa buton basışında da uyarı ver
    if (batPct < 10 && !isChargerPlugged() && btn == BTN_SHORT) {
      showingLowBatteryAlert = true;
      lowBatteryAlertTime = currentMillis;
      startTonePWM(2000, volumeLevel);
      delay(80);
      stopTonePWM();
    }

    if (btn == BTN_VERY_LONG) {
      // 2 Saniye Uzun Basış: 1 saniye boyunca anlık batarya yüzdesini göster [YENİ]
      if (currentState != STATE_BATTERY_SHOW) {
        previousState = currentState;
        currentState = STATE_BATTERY_SHOW;
        batteryShowStartTime = currentMillis;
        startTonePWM(2500, volumeLevel);
        delay(60);
        stopTonePWM();
      }
    }
    else {
      switch (currentState) {
        case STATE_STANDBY:
          if (btn == BTN_SHORT) {
            if (targetTimeSeconds > 0) {
              saveTimeToEEPROM();
              currentState = STATE_COUNTDOWN;
              lastCountdownTick = currentMillis;
            }
          } else if (btn == BTN_LONG) {
            previousState = currentState;
            currentState = STATE_VOLUME_SETTING;
            startTonePWM(3000, volumeLevel);
            delay(100);
            stopTonePWM();
          }
          break;

        case STATE_ADJUSTING:
          if (btn == BTN_SHORT) {
            if (targetTimeSeconds > 0) {
              saveTimeToEEPROM();
              currentState = STATE_COUNTDOWN;
              lastCountdownTick = currentMillis;
            }
          } else if (btn == BTN_LONG) {
            previousState = currentState;
            currentState = STATE_VOLUME_SETTING;
            startTonePWM(3000, volumeLevel);
            delay(100);
            stopTonePWM();
          }
          break;

        case STATE_COUNTDOWN:
          if (btn == BTN_SHORT) {
            remainingSeconds = targetTimeSeconds;
            currentState = STATE_STANDBY;
          } else if (btn == BTN_LONG) {
            previousState = currentState;
            currentState = STATE_VOLUME_SETTING;
            startTonePWM(3000, volumeLevel);
            delay(100);
            stopTonePWM();
          }
          break;

        case STATE_PAUSED:
          if (btn == BTN_SHORT) {
            currentState = STATE_COUNTDOWN;
            lastCountdownTick = currentMillis;
          } else if (btn == BTN_LONG) {
            previousState = currentState;
            currentState = STATE_VOLUME_SETTING;
            startTonePWM(3000, volumeLevel);
            delay(100);
            stopTonePWM();
          }
          break;

        case STATE_ALARM:
          currentState = STATE_STANDBY;
          remainingSeconds = targetTimeSeconds;
          break;

        case STATE_VOLUME_SETTING:
          saveVolumeToEEPROM();
          startTonePWM(3500, volumeLevel);
          delay(150);
          stopTonePWM();
          currentState = previousState;
          if (currentState == STATE_COUNTDOWN) {
            lastCountdownTick = millis();
          }
          break;

        case STATE_BATTERY_SHOW:
          // Butona tekrar basılırsa batarya ekranından erken çık
          currentState = previousState;
          break;
      }
    }
  }

  // 3. Durum Yönetimi ve Zamanlayıcı Mantığı
  switch (currentState) {
    case STATE_BATTERY_SHOW:
      // 1 saniye (1000 ms) geçince otomatik olarak önceki duruma dön [YENİ]
      if (currentMillis - batteryShowStartTime >= 1000) {
        currentState = previousState;
      }
      break;

    case STATE_ADJUSTING:
      if (currentMillis - lastStateChangeTime > 30000) {
        currentState = STATE_STANDBY;
      }
      break;

    case STATE_COUNTDOWN:
      if (currentMillis - lastCountdownTick >= 1000) {
        lastCountdownTick += 1000;
        if (remainingSeconds > 0) {
          remainingSeconds--;
        }
        
        if (remainingSeconds <= 0) {
          currentState = STATE_ALARM;
          alarmPatternState = 0;
          lastAlarmActionTime = currentMillis;
          lastAlarmDisplayToggle = currentMillis;
        }
      }
      break;

    case STATE_VOLUME_SETTING:
      if (currentMillis - lastStateChangeTime > 30000) {
        saveVolumeToEEPROM();
        startTonePWM(3500, volumeLevel);
        delay(150);
        stopTonePWM();
        currentState = previousState;
        if (currentState == STATE_COUNTDOWN) {
          lastCountdownTick = millis();
        }
      }
      break;

    case STATE_STANDBY:
      break;

    case STATE_PAUSED:
      if (currentMillis - lastStateChangeTime > 30000) {
        remainingSeconds = targetTimeSeconds;
        currentState = STATE_STANDBY;
      }
      break;

    case STATE_ALARM:
      break;
  }

  // Low battery Lo uyarısının 600ms sonra kendiliğinden kapanması
  if (showingLowBatteryAlert && (currentMillis - lowBatteryAlertTime >= 600)) {
    showingLowBatteryAlert = false;
  }

  // Alarm ses rutinini sürekli çalıştır
  handleAlarmSpeaker();

  // 4. Ekranın Güncellenmesi
  updateDisplay();
}

/**
 * Donanımsal Kesme Servisi (ISR)
 */
void encoderISR() {
  static unsigned long lastInterruptTime = 0;
  unsigned long interruptTime = millis();
  
  if (interruptTime - lastInterruptTime > 30) {
    int clkVal = digitalRead(PIN_ENC_CLK);
    int dtVal = digitalRead(PIN_ENC_DT);
    
    if (clkVal != dtVal) {
      encoderDelta = 1;
    } else {
      encoderDelta = -1;
    }
    encoderMoved = true;
    lastInterruptTime = interruptTime;
  }
}

/**
 * Enkoder Butonunun Okunması ve Debounce Edilmesi
 * BTN_SHORT (<1s), BTN_LONG (1s), BTN_VERY_LONG (2s)
 */
ButtonEvent checkButton() {
  static bool lastStableState = HIGH;
  static bool lastRawState = HIGH;
  static unsigned long lastDebounceTime = 0;
  static unsigned long buttonPressTime = 0;
  static int pressPhase = 0; // 0: nötr, 1: Long (1s) verildi, 2: VeryLong (2s) verildi

  bool rawState = digitalRead(PIN_ENC_SW);
  ButtonEvent event = BTN_NONE;
  unsigned long currentMillis = millis();

  if (rawState != lastRawState) {
    lastDebounceTime = currentMillis;
  }
  lastRawState = rawState;

  if ((currentMillis - lastDebounceTime) > 50) {
    if (rawState != lastStableState) {
      lastStableState = rawState;

      if (lastStableState == LOW) {
        buttonPressTime = currentMillis;
        pressPhase = 0;
      } 
      else {
        if (pressPhase == 0) {
          unsigned long pressDuration = currentMillis - buttonPressTime;
          if (pressDuration < 1000) {
            event = BTN_SHORT;
          }
        }
      }
    }
  }

  if (lastStableState == LOW) {
    unsigned long pressDuration = currentMillis - buttonPressTime;
    if (pressPhase == 0 && pressDuration >= 1000 && pressDuration < 2000) {
      pressPhase = 1;
      event = BTN_LONG;
    }
    else if (pressPhase == 1 && pressDuration >= 2000) {
      pressPhase = 2;
      event = BTN_VERY_LONG;
    }
  }

  return event;
}

/**
 * Batarya Voltajından Yüzdeye (%0 - %100) Dönüşüm
 */
int getBatteryPercentage() {
  int rawADC = analogRead(PIN_BATTERY_SENSE);
  float voltage = (rawADC * 5.0) / 1023.0;
  
  if (voltage >= 4.20) return 100;
  if (voltage <= 3.00) return 0;
  
  int percent = (int)((voltage - 3.00) * 100.0 / (4.20 - 3.00));
  if (percent > 100) percent = 100;
  if (percent < 0) percent = 0;
  return percent;
}

/**
 * Şarj Kablosu Takılı mı Kontrol Et
 */
bool isChargerPlugged() {
  int rawADC = analogRead(PIN_CHARGER_SENSE);
  return (rawADC > 600); // ~3.0V üzeri okuma şarj takılı olduğunu gösterir
}

/**
 * Sistem Durumuna Göre TM1637 Ekranının Güncellenmesi
 */
void updateDisplay() {
  unsigned long currentMillis = millis();
  
  static SystemState lastState = (SystemState)-1;
  static bool lastColonState = false;
  static bool lastAlarmToggle = false;
  static int lastVol = -1;
  static long lastRemSecs = -1;
  static long lastTarSecs = -1;
  static bool lastLowAlertState = false;

  bool stateChanged = (currentState != lastState);
  if (stateChanged) {
    lastState = currentState;
    display.clear();
  }

  // Düşük batarya uyarısı öncelikli gösterimi (Lo uyarısı aktifken)
  if (showingLowBatteryAlert) {
    if (!lastLowAlertState) {
      lastLowAlertState = true;
      display.setSegments(SEG_LO); // " Lo "
    }
    return;
  }
  lastLowAlertState = false;

  switch (currentState) {
    case STATE_BATTERY_SHOW: {
      // 2 saniye basıldığında 1 saniye boyunca ekranda anlık pil yüzdesini göster (Örn: b-85 veya b100)
      display.setBrightness(7);
      int pct = getBatteryPercentage();
      uint8_t segs[4];
      segs[0] = 0x7C; // 'b'
      segs[1] = 0x40; // '-'
      if (pct >= 100) {
        segs[1] = display.encodeDigit(1);
        segs[2] = display.encodeDigit(0);
        segs[3] = display.encodeDigit(0);
      } else if (pct < 10) {
        segs[2] = 0x00;
        segs[3] = display.encodeDigit(pct);
      } else {
        segs[2] = display.encodeDigit(pct / 10);
        segs[3] = display.encodeDigit(pct % 10);
      }
      display.setSegments(segs);
      break;
    }

    case STATE_STANDBY: {
      display.setBrightness(1);
      
      if (currentMillis - lastColonToggle >= 800) {
        lastColonToggle = currentMillis;
        colonState = !colonState;
      }
      
      int mins = targetTimeSeconds / 60;
      int secs = targetTimeSeconds % 60;
      
      if (stateChanged || colonState != lastColonState || targetTimeSeconds != lastTarSecs) {
        lastColonState = colonState;
        lastTarSecs = targetTimeSeconds;
        display.showNumberDecEx(mins * 100 + secs, colonState ? 0b01000000 : 0, true);
      }
      break;
    }
    
    case STATE_ADJUSTING: {
      display.setBrightness(4);
      int mins = targetTimeSeconds / 60;
      int secs = targetTimeSeconds % 60;
      
      if (stateChanged || targetTimeSeconds != lastTarSecs) {
        lastTarSecs = targetTimeSeconds;
        display.showNumberDecEx(mins * 100 + secs, 0b01000000, true);
      }
      break;
    }
    
    case STATE_COUNTDOWN: {
      display.setBrightness(7);
      
      if (currentMillis - lastColonToggle >= 500) {
        lastColonToggle = currentMillis;
        colonState = !colonState;
      }
      
      int mins = remainingSeconds / 60;
      int secs = remainingSeconds % 60;
      
      if (stateChanged || colonState != lastColonState || remainingSeconds != lastRemSecs) {
        lastColonState = colonState;
        lastRemSecs = remainingSeconds;
        display.showNumberDecEx(mins * 100 + secs, colonState ? 0b01000000 : 0, true);
      }
      break;
    }
    
    case STATE_PAUSED: {
      display.setBrightness(7);
      int mins = remainingSeconds / 60;
      int secs = remainingSeconds % 60;
      
      if (stateChanged || remainingSeconds != lastRemSecs) {
        lastRemSecs = remainingSeconds;
        display.showNumberDecEx(mins * 100 + secs, 0b01000000, true);
      }
      break;
    }
    
    case STATE_ALARM: {
      display.setBrightness(7);
      
      if (currentMillis - lastAlarmDisplayToggle >= 400) {
        lastAlarmDisplayToggle = currentMillis;
        alarmDisplayToggleState = !alarmDisplayToggleState;
      }
      
      if (stateChanged || alarmDisplayToggleState != lastAlarmToggle) {
        lastAlarmToggle = alarmDisplayToggleState;
        if (alarmDisplayToggleState) {
          display.showNumberDecEx(0, 0b01000000, true);
        } else {
          display.setSegments(SEG_END); 
        }
      }
      break;
    }
    
    case STATE_VOLUME_SETTING: {
      display.setBrightness(7);
      
      if (stateChanged || volumeLevel != lastVol) {
        lastVol = volumeLevel;
        uint8_t segments[4];
        segments[0] = 0x3E; // 'U'
        segments[1] = 0x40; // '-'
        if (volumeLevel < 10) {
          segments[2] = 0x00;
          segments[3] = display.encodeDigit(volumeLevel);
        } else {
          segments[2] = display.encodeDigit(1);
          segments[3] = display.encodeDigit(0);
        }
        display.setSegments(segments);
      }
      break;
    }
  }
}

/**
 * MOSFET Hoparlör Sürücü Rutini
 */
void handleAlarmSpeaker() {
  static bool wasAlarmRunning = false;
  unsigned long currentMillis = millis();
  unsigned long elapsed = currentMillis - lastAlarmActionTime;

  if (currentState != STATE_ALARM) {
    if (wasAlarmRunning) {
      stopTonePWM();
      alarmPatternState = 0;
      wasAlarmRunning = false;
    }
    return;
  }

  wasAlarmRunning = true;

  switch (alarmPatternState) {
    case 0:
      startTonePWM(2500, volumeLevel); 
      lastAlarmActionTime = currentMillis;
      alarmPatternState = 1;
      break;
      
    case 1:
      if (elapsed >= 100) {
        startTonePWM(3500, volumeLevel);
        lastAlarmActionTime = currentMillis;
        alarmPatternState = 2;
      }
      break;
      
    case 2:
      if (elapsed >= 100) {
        alarmPatternState = 0;
      }
      break;
  }
}

void saveTimeToEEPROM() {
  byte unitsToSave = targetTimeSeconds / 30;
  if (EEPROM.read(EEPROM_ADDR_TIME) != unitsToSave) {
    EEPROM.update(EEPROM_ADDR_TIME, unitsToSave);
  }
  if (EEPROM.read(EEPROM_ADDR_MAGIC) != EEPROM_MAGIC_VAL) {
    EEPROM.update(EEPROM_ADDR_MAGIC, EEPROM_MAGIC_VAL);
  }
}

void loadTimeFromEEPROM() {
  byte magic = EEPROM.read(EEPROM_ADDR_MAGIC);
  if (magic == EEPROM_MAGIC_VAL) {
    byte loadedUnits = EEPROM.read(EEPROM_ADDR_TIME);
    if (loadedUnits <= 198) {
      targetTimeSeconds = (long)loadedUnits * 30;
      return;
    }
  }
  targetTimeSeconds = DEFAULT_TIME_SECONDS;
}
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

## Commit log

2026-05-31 initial commit: premium kitchen timer project, dynamic encoder steps, 30ms debounce, and 3D enclosure models
    [kutu_govde.stl, kutu_kapak.stl, kutu_tasarimi.scad]
2026-05-31 refactor: rename image files for encoder and mosfet to descriptive names
2026-05-31 feat: implement hardware PWM volume control (1-10) and temporary 3-second test starting time
2026-05-31 perf: optimize display update rendering and enable glitch-free continuous PWM frequency transitions
    [kitchen_timer.ino]
2026-05-31 fix: resolve duplicate closing brace in updateDisplay function to fix compilation error
    [kitchen_timer.ino]
2026-05-31 fix: reset TCNT1 on ICR1 change to prevent Timer 1 register mismatch audio cutout race condition
    [kitchen_timer.ino]
2026-05-31 feat: resize 3D box and cover to 60x100mm in OpenSCAD and recompile STL files
    [kutu_govde.stl, kutu_kapak.stl, kutu_tasarimi.scad]
2026-06-04 feat: change short press during countdown to immediately stop and reset timer to target time
    [kitchen_timer.ino]
2026-06-06 Kutu boyutlari 80x120 olarak guncellendi ve yeni STL dosyalari uretildi
    [kutu_govde.stl, kutu_kapak.stl, kutu_tasarimi.scad]
2026-06-06 Kutu boyutlari icten ice 80x140 (distan disa 84x144) olarak guncellendi ve yeni STL dosyalari uretildi
    [kutu_govde.stl, kutu_kapak.stl, kutu_tasarimi.scad]
2026-07-23 18650 Li-ion pil, LX-LCBST sarj modulu, A0/A1 batarya/sarj okuma, 1sn batarya yuzdesi gosterimi ve Lo uyari bipi eklendi
    [kutu_govde.stl, kutu_kapak.stl]
2026-07-23 Arduino Nano A0 (Batarya Sense) ve A1 (Sarj Sense) baglanti hatlari semada tamamlandi
2026-07-23 LX-LCBST sarj modulu uzerindeki IN+ (5V) ve IN- (GND) lehim padleri semada belirginlestirildi
2026-07-23 IN- gnd kablosu dikey ana GND rayina lehim noktasi ile baglandi
2026-07-23 Kablo hatlari 90 derece dik acili ve kusursuz cizildi, 4x 47 Ohm yerine tek 10 Ohm 1W koruma direnci tum belgelere uygulandi
2026-07-23 10 Ohm 1W direncten hoparlore giden kablo mavi renge donusturuldu ve IN- gnd kablosu kusursuz duzlukte yeniden cizildi
2026-07-23 microcontroller-schematic-generator yetenegi ile otomatik uretilen baglanti_semasi_generator.html ve .svg dosyasi eklendi
2026-07-23 GPT tarafindan sunulan 7 elektronik tavsiye degerlendirildi: ON/OFF anahtar semaya eklendi, A0 ve A1 pinlerine 10k koruma direncleri eklendi, hoparlor direnci 10 Ohm 2W yapildi, D2/D3 pin etiketleri 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
2026-07-23 Hoparlor koruma direnci 2x 10 Ohm 1W Paralel (5 Ohm / 2W esdeger) olarak tum proje dosyalarinda guncellendi
2026-07-23 2x 10 Ohm 1W Paralel direnç blogu ve basligi ferah beyaz alana kaydirildi, hicbir yazi ve kutu çakisismasi kalmadi
